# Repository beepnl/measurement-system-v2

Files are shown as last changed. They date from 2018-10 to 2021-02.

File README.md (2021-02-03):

# BEEP - Measurement system
This is a repo containing the files to create the open source hardware for the Beep measurement system.

## Measurement system parts

The measurement system casing is designed as both an electonics/sensor housing, as well as a weighing frame. The outer casing is assembled in four pieces (2 tops, 2 bottoms) out of 18mm thick plate 'Betonplex' (glued multiplex with water resistant top and bottom layer). The wooden top and bottom are connected together by the 2 weight sensor (aluminium) blocks, held in place by 2 weight sensor brackets each. The left and right part are held together with 2 stainless steel tubes, that are screwed on the wood. At one side tightly, using wood parkers, at the other side loosely, using m4 bolts that go inside the inserts. By this connection, the total size of the frame is adjustable for different types of hives. 

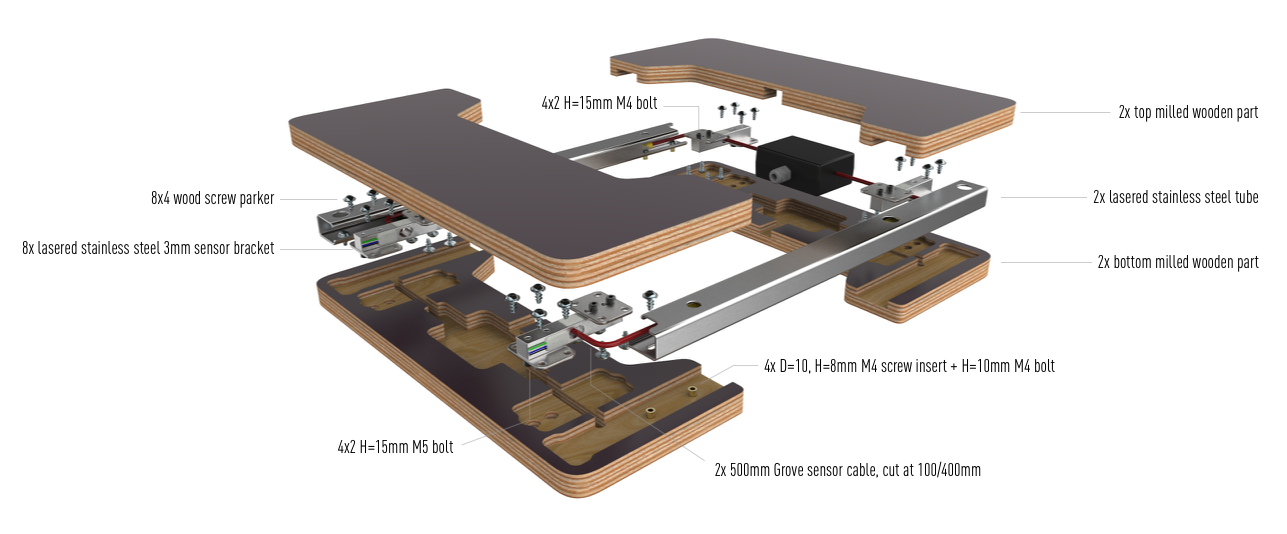
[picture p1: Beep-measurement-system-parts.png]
BEEP measurement system casing


## Frame
The folder 'frame' contains two folders: wood and stainless steel. 

### Wood
The 2D drawings in both Illustrator format and DXF (required by most milling parties).

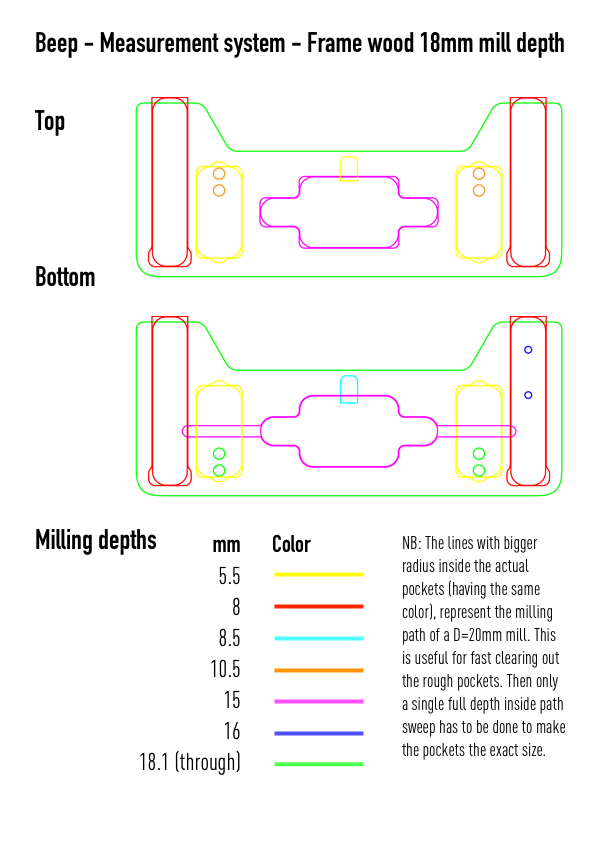
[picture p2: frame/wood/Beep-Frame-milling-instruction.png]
BEEP measurement system casing - Milling instruction


This is a picture of the milling software, with which we mill 42 pieces (21 tops, 21 bottoms) out of an 2440 x 1220 x 18 mm Betonplex.

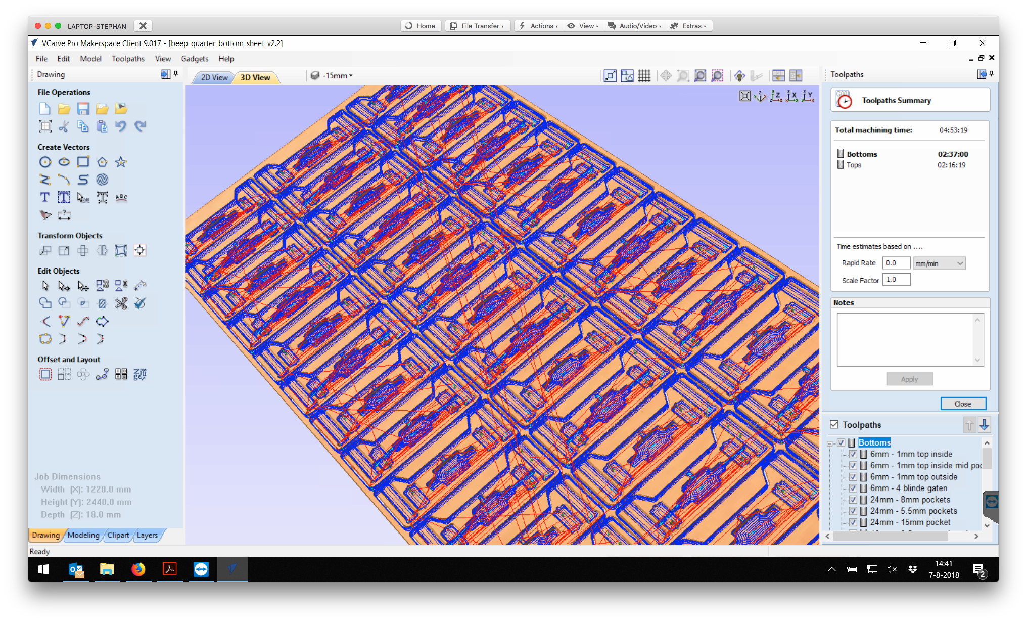
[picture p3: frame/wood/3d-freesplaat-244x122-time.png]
BEEP measurement system - Milling process


### Stainless steel
The 3D and 2D drawings of the stainless steel tube, and the sensor bracket are in this folder. They can be ordered at companies lasering steel.

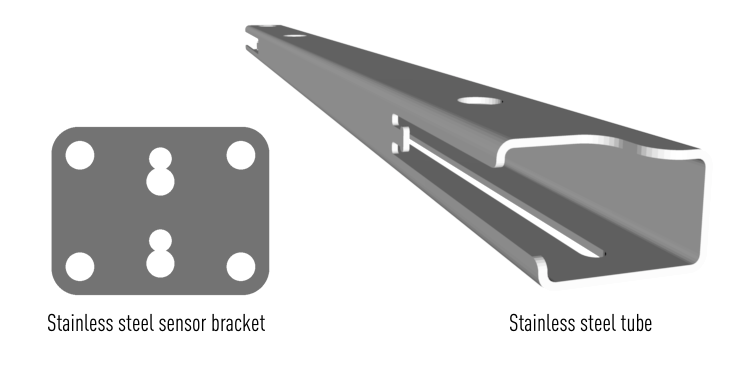
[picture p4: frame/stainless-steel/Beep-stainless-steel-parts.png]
BEEP measurement system - Stainless steel parts


## Electronics
The electronics of the measurement system are bundled together on the Beep PCB, which connects an Arduino, a LoRa (wireless network) chip and the sensors via Grove connectors together.

The folder 'electronics' contains two folders: gerber and kicad.

With the Gerber files, you can directly order a PCB. It contains all files required for the manufacturing of the PCB. 

With the Kicad files, you can edit the PCB and it's components in the open source PCB creation software Kicad (http://kicad-pcb.org/).

### Schematic

*NB: There is an error in the PCB, the one wire temperature sensor DS18b20 cannot work on analog port A7 (the A6 and A7 IO pins can only be used as analog pins, not as digital IO). So you have to use A4, or A5 to connect one wire sensor(s) to. So you also have to add the 4k7 resistor between V+ and the one wire data pin yourself, since the resistor on the PCB is connected to V+ and A7.*

The schematic can be found in the PDF (https://github.com/beepnl/measurement-system-v2/blob/master/electronics/Beep-pcb-v1.4-schematic.pdf)

### PCB
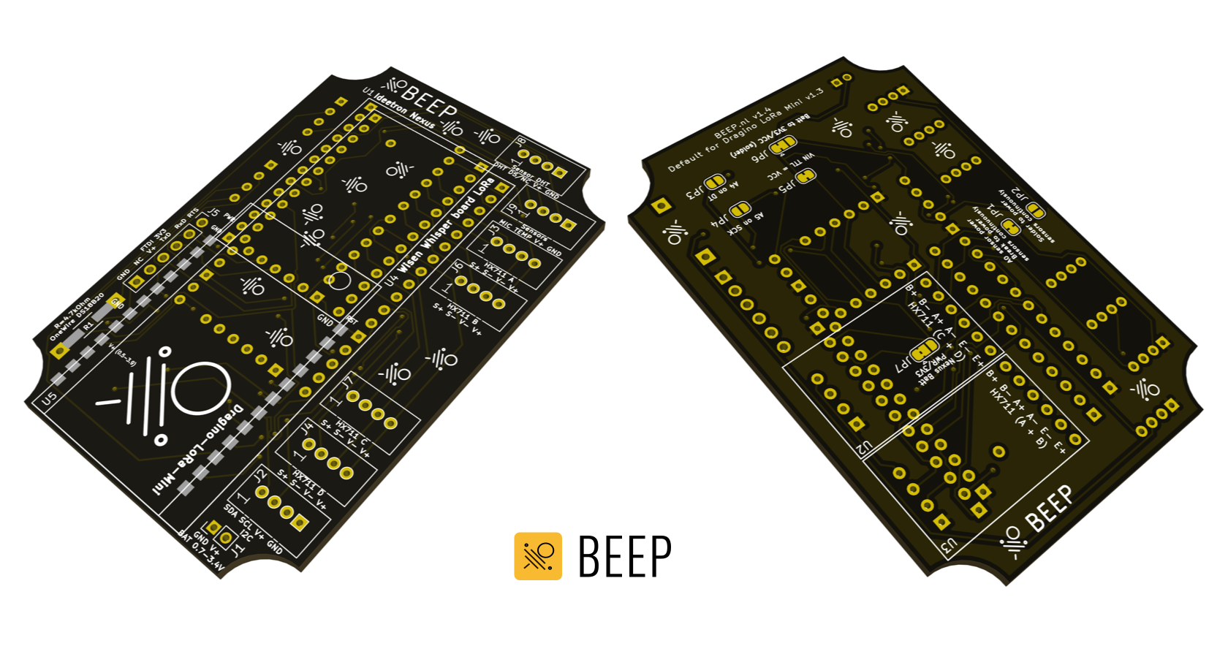
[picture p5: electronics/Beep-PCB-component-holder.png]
BEEP measurement system - PCB


### Assembly
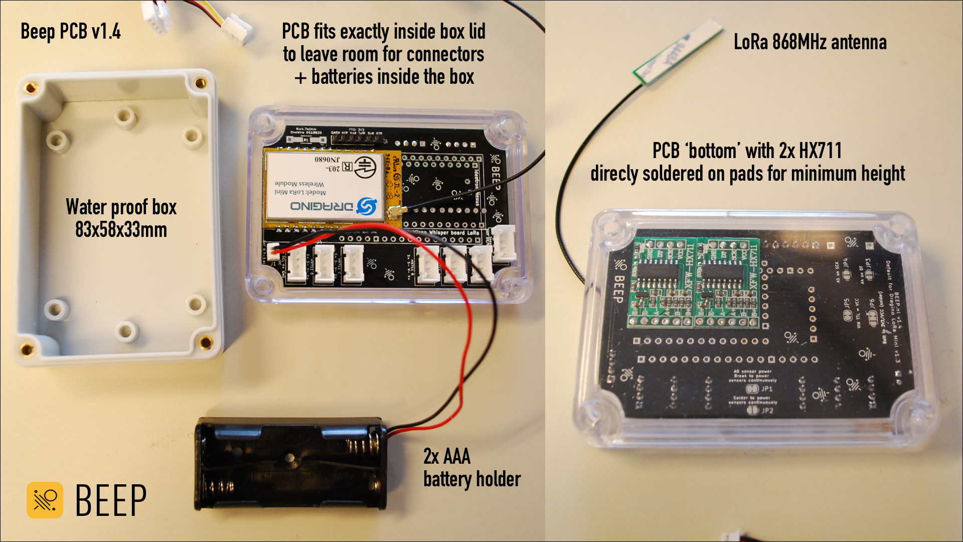
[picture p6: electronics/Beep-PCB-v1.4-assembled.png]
BEEP measurement system - PCB


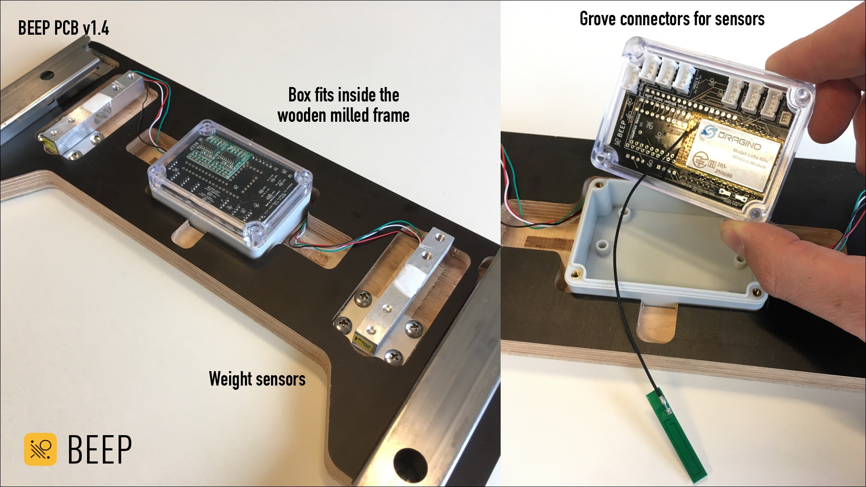
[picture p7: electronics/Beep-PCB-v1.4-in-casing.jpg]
BEEP measurement system - PCB


## Firmware
In the 'firmware' folder, the ultra low power Arduino code is shared to use with the PCB and complete the measurement system.

Place the folder 'Beep-low-power' inside your Arduino folder and set up your own LoRa connection details to send the data.
Send an e-mail to pim@beep.nl, to add your Measurement system Device EUI to your Beep app account and receive it's measurements in the app.

## Improvements
If you have improvements, or ideas for creating a better frame, please send an e-mail to pim@beep.nl explaining your thoughts. Or just fork this repo, and do a pull request with you adjustments, or additions.

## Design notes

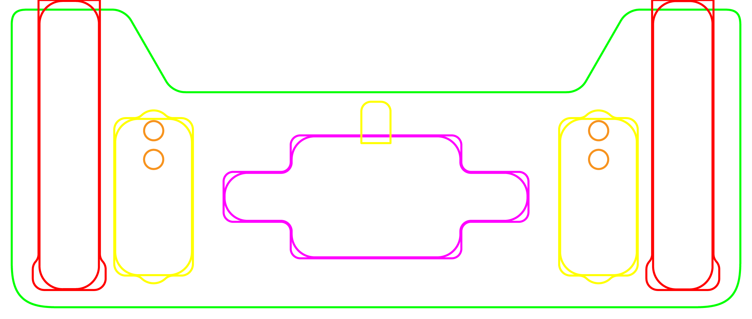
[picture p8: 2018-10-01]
frame/wood/beep_quarter_top_v2.2.png

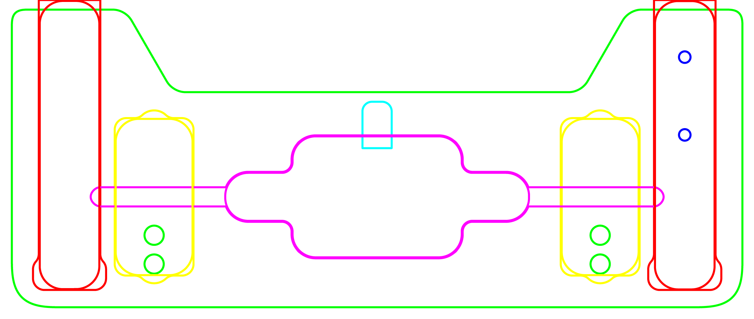
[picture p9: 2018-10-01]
frame/wood/beep_quarter_bottom_v2.2.png

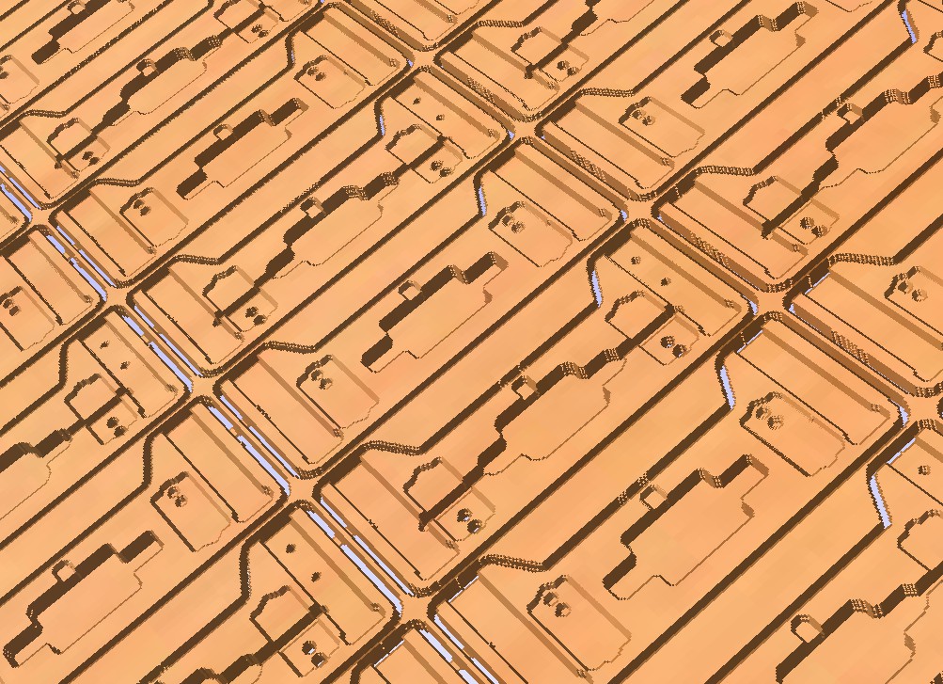
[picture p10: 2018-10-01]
frame/wood/3d-detail-244x122.jpg

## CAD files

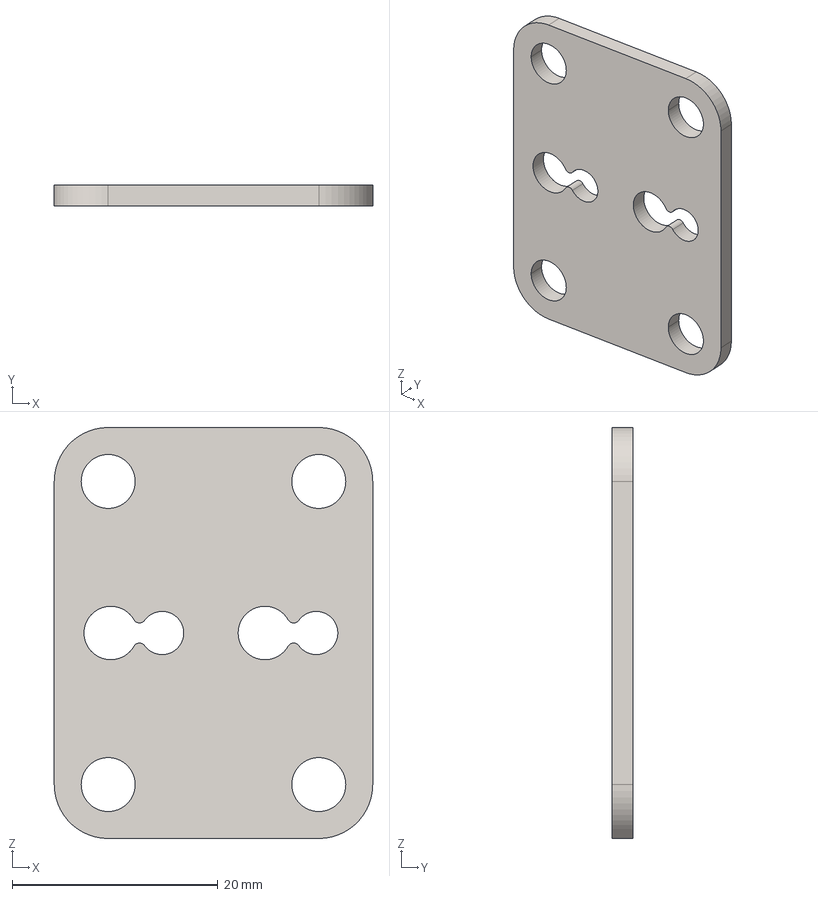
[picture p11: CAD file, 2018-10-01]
frame/stainless-steel/Beep_weightsensor_bracket__2018-05-10.stp
31.0 x 2.00 x 40.0 mm

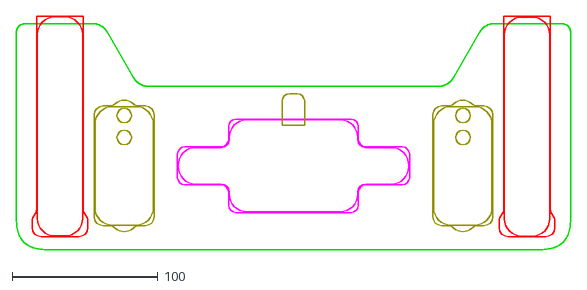
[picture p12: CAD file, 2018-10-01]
frame/wood/beep_quarter_top_v2.2.dxf
380.0 x 160.0

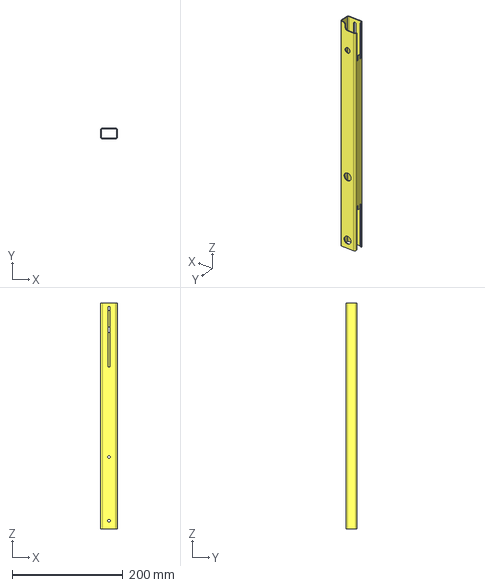
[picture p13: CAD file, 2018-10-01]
frame/stainless-steel/Beep_Tube__2018_07_23.stp
30.0 x 20.0 x 408.5 mm

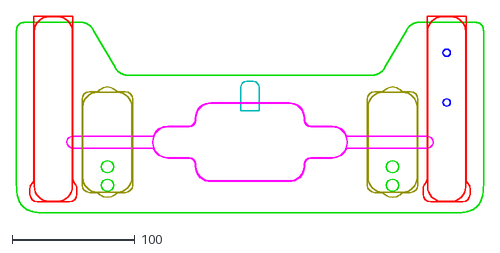
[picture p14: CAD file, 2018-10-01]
frame/wood/beep_quarter_bottom_v2.2.dxf
380.0 x 160.0

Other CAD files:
frame/stainless-steel/Beep_tube__2018_07_23.stl

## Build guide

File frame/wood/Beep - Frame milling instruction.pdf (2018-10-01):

## Beep - Measurement system - Frame wood 18mm mill depth

## Top

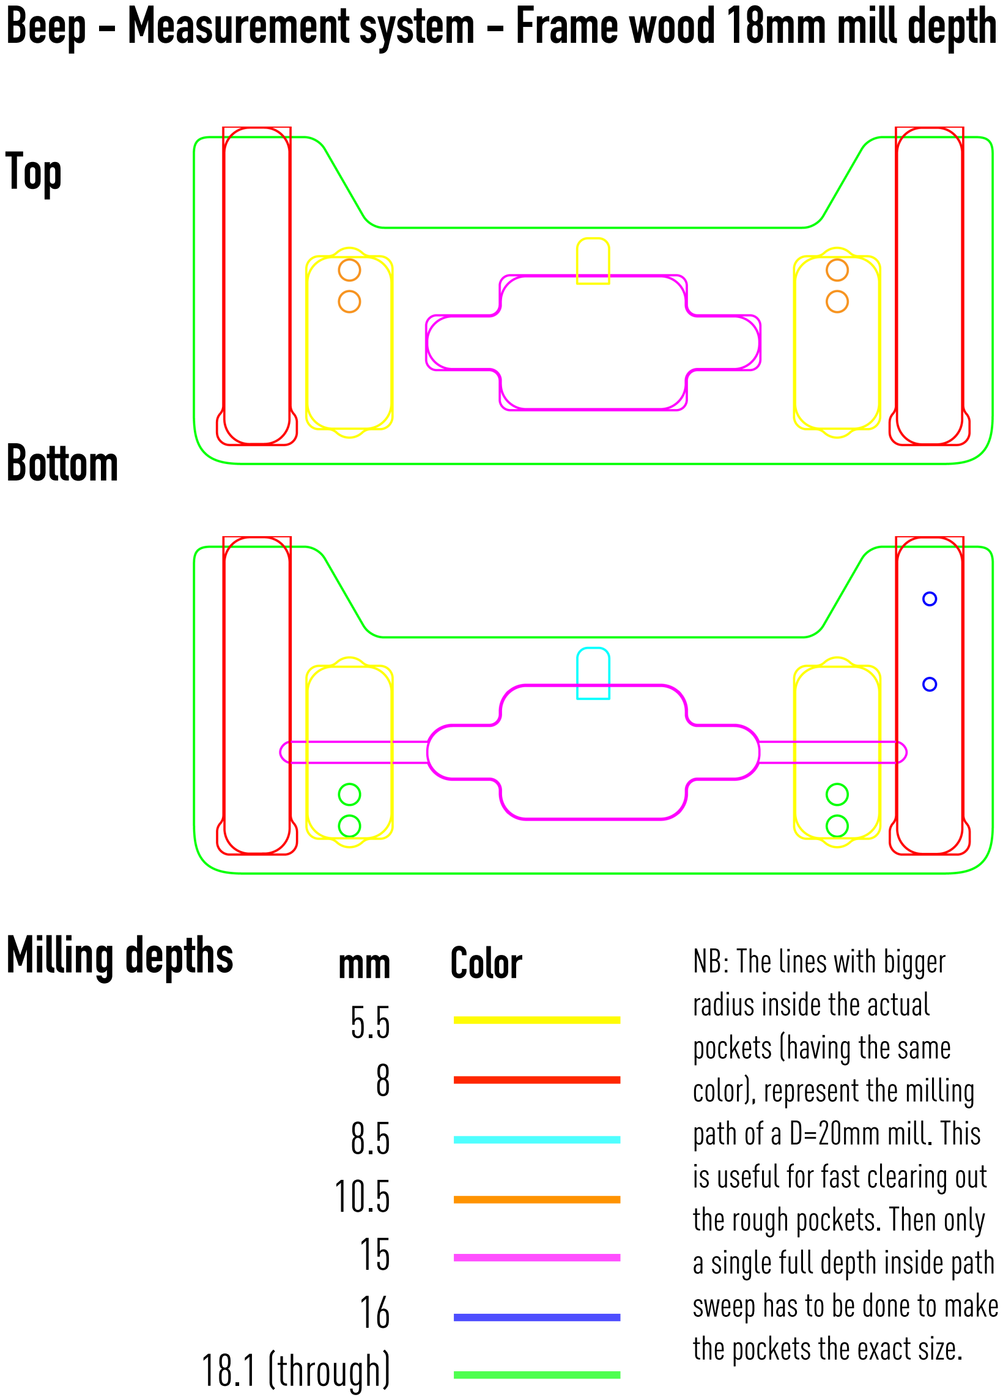
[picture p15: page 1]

## Bottom

Milling depths | mm
| 5.5
| 8
| 8.5
| 10.5
| 15
| 16

## 18.1 (through)

Color | NB: The lines with bigger radius inside the actual pockets (having the same color), represent the milling path of a D=20mm mill. This is useful for fast clearing out the rough pockets. Then only a single full depth inside path sweep has to be done to make the pockets the exact size.

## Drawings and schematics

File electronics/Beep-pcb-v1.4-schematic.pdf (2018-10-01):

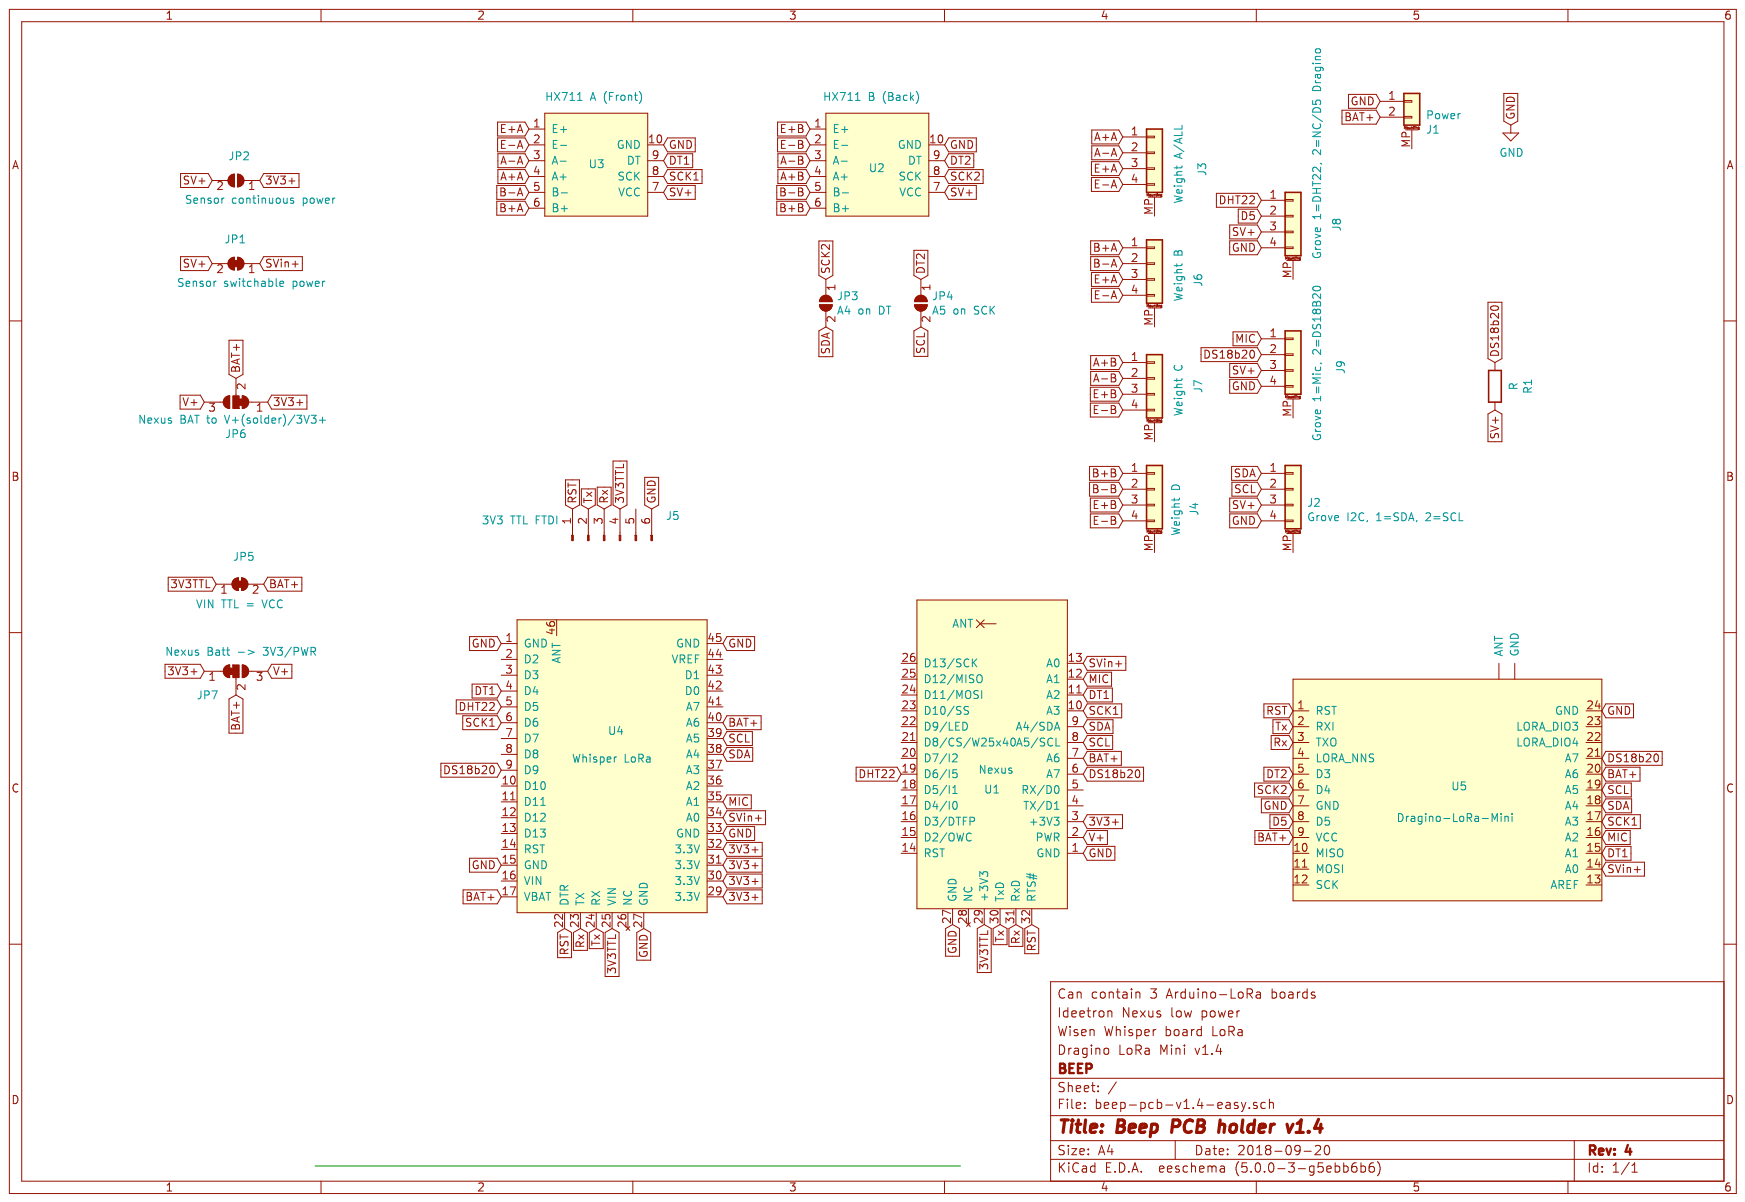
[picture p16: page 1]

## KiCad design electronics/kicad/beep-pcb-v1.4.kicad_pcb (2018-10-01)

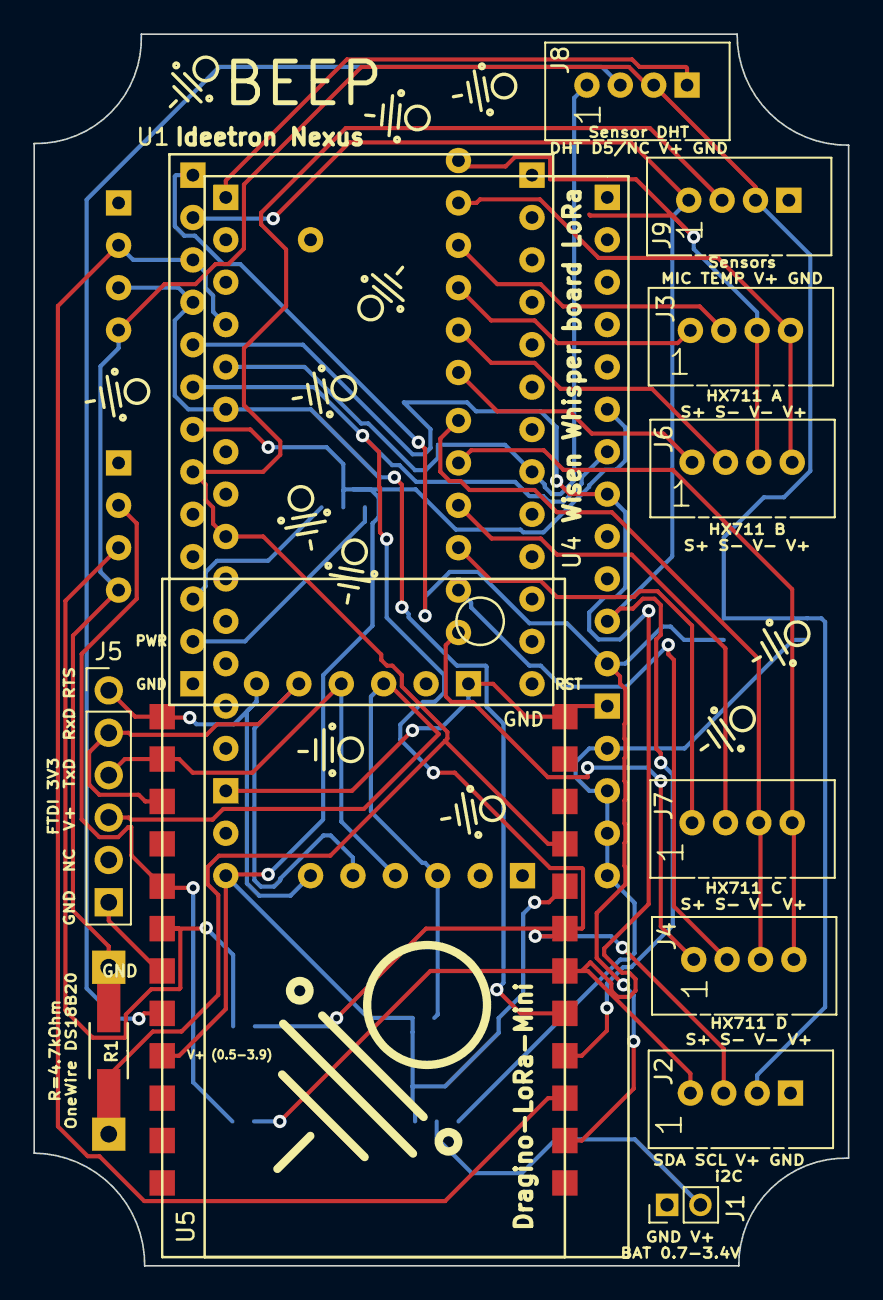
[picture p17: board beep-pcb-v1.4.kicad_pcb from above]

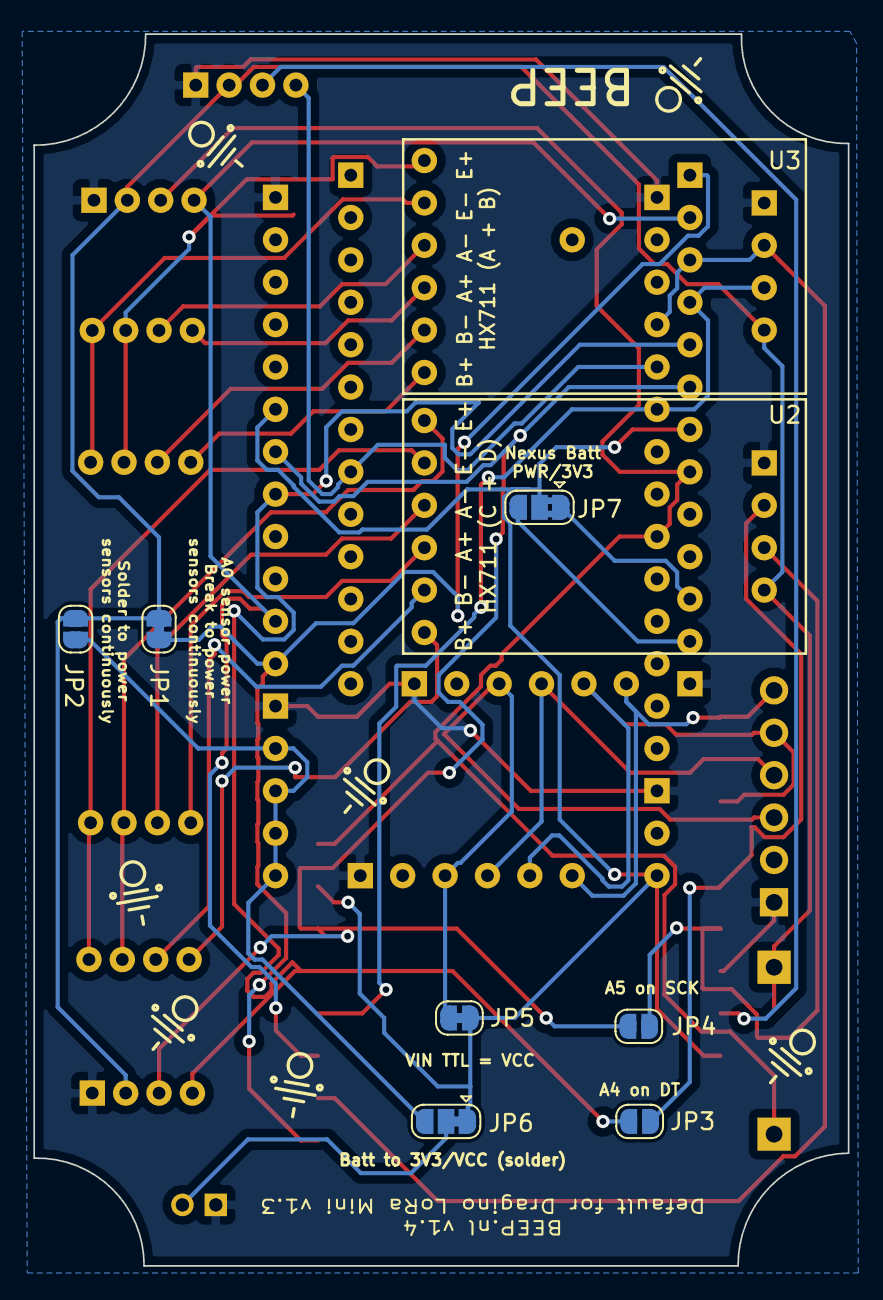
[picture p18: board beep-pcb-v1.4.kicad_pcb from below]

Board: 2 copper layers, 48.8 x 73.8 mm, 22 parts (9 on the bottom side), 34 nets.

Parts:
J1: Power; Pin_Header_Straight_1x02_Pitch2.00mm
J2: Grove I2C, 1=SDA, 2=SCL; Grove_1x04
J3: Weight A/ALL; Grove_1x04
J4: Weight D; Grove_1x04
J5: 3V3 TTL FTDI; Pin_Header_Straight_1x06_Pitch2.54mm
J6: Weight B; Grove_1x04
J7: Weight C; Grove_1x04
J8: Grove 1=DHT22, 2=NC/D5 Dragino; Grove_1x04
J9: Grove 1=Mic, 2=DS18B20; Grove_1x04
JP1: Sensor switchable power; SolderJumper-2_P1.3mm_Bridged_RoundedPad1.0x1.5mm
JP2: Sensor continuous power; SolderJumper-2_P1.3mm_Open_RoundedPad1.0x1.5mm
JP3: A4 on DT; SolderJumper-2_P1.3mm_Open_RoundedPad1.0x1.5mm
JP4: A5 on SCK; SolderJumper-2_P1.3mm_Open_RoundedPad1.0x1.5mm
JP5: VIN TTL = VCC; SolderJumper-2_P1.3mm_Bridged_RoundedPad1.0x1.5mm
JP6: Batt to VCC/3V3 (solder); SolderJumper-3_P1.3mm_Bridged12_RoundedPad1.0x1.5mm
JP7: Nexus Batt -> 3V3/PWR; SolderJumper-3_P1.3mm_Bridged2Bar12_RoundedPad1.0x1.5mm
R1: R; Resistor_SMD+THTuniversal_1206_RM10_HandSoldering
U1: Nexus
U2, U3: HX711
U4: Whisper LoRa; Whisper_Lora
U5: Dragino-LoRa-Mini; Dragino LoRa Mini

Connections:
+3V3: JP2.1, JP6.3, U4.29, U4.30, U4.31, U4.32
+BATT: J1.2, JP6.2
+VDC: JP5.2, JP6.1, JP7.2, U1.7, U4.17, U4.40, U5.9, U5.20
GND: J1.1, J2.4, J5.6, J8.4, J9.4, U1.1, U1.27, U2.10, U3.10, U4.1, U4.15, U4.27, U4.33, U4.45, U5.7, U5.24
unnamed: J2.1, JP3.2, U1.9, U4.38, U5.18
unnamed: J2.2, JP4.2, U1.8, U4.39, U5.19
unnamed: J2.3, J8.3, J9.3, JP1.2, JP2.2, R1.1, U2.7, U3.7
unnamed: J3.1, U3.4
unnamed: J3.2, U3.3
unnamed: J3.3, J6.3, U3.1
unnamed: J3.4, J6.4, U3.2
unnamed: J4.1, U2.6
unnamed: J4.2, U2.5
unnamed: J4.3, J7.3, U2.1
unnamed: J4.4, J7.4, U2.2
unnamed: J5.1, U1.32, U4.22, U5.1
unnamed: J5.2, U1.31, U4.23, U5.3
unnamed: J5.3, U1.30, U4.24, U5.2
unnamed: J5.4, JP5.1, U1.29, U4.25
unnamed: J6.1, U3.6
unnamed: J6.2, U3.5
unnamed: J7.1, U2.4
unnamed: J7.2, U2.3
unnamed: J8.1, U1.19, U4.5
unnamed: J8.2, U5.8
unnamed: J9.1, U1.12, U4.35, U5.15
unnamed: J9.2, R1.2, U1.6, U4.9, U5.21
unnamed: JP1.1, U1.13, U4.34, U5.14
unnamed: JP3.1, U2.9, U5.5
unnamed: JP4.1, U2.8, U5.6
unnamed: JP7.1, U1.3
unnamed: JP7.3, U1.2
unnamed: U1.10, U3.8, U4.6, U5.17
unnamed: U1.11, U3.9, U4.4, U5.16

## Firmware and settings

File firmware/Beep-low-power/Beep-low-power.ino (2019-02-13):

/*******************************************************************************
 * BEEP LoRa code, adjusted for Dragino pinout
 *
 * Many thanks to Ideetron, Maarten Westenberg, Thomas Telkamp and Matthijs Kooijman
 * porting the LMIC stack to Arduino IDE and Gerben den Hartog for his tiny
 * stack implementation with the AES library that we used in the LMIC stack.
 *
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
 * This example sends a valid LoRaWAN packet with sensor values read.
 *
 * Note: LoRaWAN per sub-band duty-cycle limitation is enforced (1% in g1,
 *  0.1% in g2).
 *
 * Change DevAddr to a unique address for your node
 * See http://thethingsnetwork.org/wiki/AddressSpace
 *
 * Define you own LoRa connection details in lorawan_def.h (from row 238):
 * struct.activation_method -> OVER_THE_AIR_ACTIVATION, or ACTIVATION_BY_PERSONALISATION
 * struct.back_end        -> The_Things_Network, KPN (NL)
 * struct.Session, or OTAA (depending on the chosen activation_method)
 *
 * v7 added:
 *     - w_fl, w_fr, w_bl, w_br
 *     - H   -> *2 (range 0-200)
 *     - T   -> -10 -> +40 range (+10, *5), so 0-250 is /5, -10
 *     - W_E -> -20 -> +80 range (/2, +10, *5), so 0-250 is /5, -10, *2
 *
 * v8 added:
 *     - Measurement timing can be set from sensor_sample_sec (min) to max_send_timeout (max)
 *
 * v9 added:
 *     - T/H DHT22 based on SimpleDHT.h, because std DHT.h has timing issue after getBandgap()
 *
 *******************************************************************************/

// Enable debug prints to serial monitor
#define MY_DEBUG_NO // MY_DEBUG_NO (for production), MY_DEBUG_SENS, MY_DEBUG

#if defined(__AVR__)
#include <avr/pgmspace.h>
#include <Arduino.h>
#elif defined(ARDUINO_ARCH_ESP8266)
#include <ESP.h>
#elif defined(__MKL26Z64__)
#include <Arduino.h>
#else
#error Unknown architecture in aes.cpp
#endif

#include <avr/power.h>
#include <avr/sleep.h>
#include <stdbool.h>

#include <LowPower.h>

#include <SPI.h>
#include <EEPROM.h>

#include "AES-128.h"
#include "Encrypt.h"
#include "Nexus_LoRaWAN.h"
#include "spi_nexus.h" // for RFM_sleep function
#include "RFM95.h"
#include "LoRaMAC.h"
#include "timers.h"
#include "lorawan_def.h"

//#include "DHT.h"   // has timing problems in reltion with battery voltage read script
#include <SimpleDHT.h> // so use SimpleDHT.h in stead.
#include "HX711.h"
#include <DS18B20.h> // much smaller than DallasTemperature
//#include <stdlib.h>

/******************************************************************************************
                  PIN DEFINITIONS
******************************************************************************************/

// Audio samples
// Use A2 ADC in free running mode
#define MIC_SENSE_PIN A2
#define SENSOR_POWER A0
#define LOG_OUT 1 // use the logarithmic output function
#define FHT_N 128 // set to 128 point fht (in stead of 256)
#define DIVIDE_FREQ_BY 60 // max freq is 18kHz at 16MHz processor, so factor 60 is max 300Hz sampling, so each band is 5Hz (@FHT_N=128)
#define MEASURE_THRESHOLD 5 // 0-100 threshold for counting values
#include <FHT.h>

// DHT22
#define DHTPIN 5
//#define DHTTYPE DHT22

// Weight sensors
#define DAT_FRONT A1
#define CLK_FRONT A3
#define DAT_BACK 3
#define CLK_BACK 4

// One wire temp DS18B20, does not work on A6/A7 (analog only)
#define ONEW A4

/******************************************************************************************
                  GLOBAL VARIABLES
******************************************************************************************/

bool large_diff = false;

uint8_t  battery_dV        = 0;  // 30 = 3.0V
uint16_t times_not_sent    = 0;  // times not sent counter
uint16_t max_send_timeout  = 3600; // 10800 = 3 hours, 3600 = 1 hour. Has to be a multiple of 8, max 65536 = 1092 min = 18 hour
uint16_t sensor_sample_sec = 904; // 3600 = 1 hour, 904 = 15 min, 296 = 5 min. Has to be a multiple of 8, max 65536 = 1092 min = 18 hour

  // Interrupt variables.
  volatile bool LORA_SEND;

  double read_supply_voltage (void);

  sAPP        app;    //  Application variables
  sLoRaWAN    lora;   //  See the Nexus_Lorawan.h file for the settings of this structure.

  // Initialize the LoRaWAN stack.
  LORAMAC     lorawan (&lora);

/******************************************************************************************
                  INTERRUPTS
******************************************************************************************/
/*
  @Brief  Interrupt vector for the alarm of the MCP7940 Real Time Clock.
*/
ISR(INT1_vect)
{
  // Set the boolean to true to indicate that the RTC alarm has occurred. Do not use I2C functions or long delays here, but handle that in the main loop.
  LORA_SEND = true;
}

/*
  @Brief  Interrupt vector for Timer1 which is used to time the Join and Receive windows for timeslot 1 and timelsot 2
*/
ISR(TIMER1_COMPA_vect)
{
  // Increment the timeslot counter variable for timing the JOIN and receive delays.
  lora.timeslot++;
}


/******************************************************************************************
                  SENSOR
******************************************************************************************/

// FHT
uint16_t sound_total    = 0;
uint16_t sound_bee_fan4 = 0;
uint16_t sound_bee_fan6 = 0;
uint16_t sound_bee_fan9 = 0;
uint16_t sound_bee_fly  = 0;

float w_fl_offset = 0;
float w_fr_offset = 0;
float w_bl_offset = 0;
float w_br_offset = 0;

uint8_t w_e_hist[] = {0,0,0};
uint8_t t_e_hist[] = {0,0,0};
uint8_t t_i_hist[] = {0,0,0};
uint8_t h_e_hist[] = {0,0,0};
uint8_t s_t_hist[] = {0,0,0};
uint8_t b_v_hist[] = {0,0,0};

// HX711
int16_t weight_calib = 5000; // -5000 for red to E+ and black to E-, else 5000
HX711 weight_front(DAT_FRONT, CLK_FRONT);
HX711 weight_back(DAT_BACK, CLK_BACK);

// DHT 22
SimpleDHT22 dht(DHTPIN);
//DHT dht(DHTPIN, DHTTYPE);

// One wire
OneWire oneWire(ONEW);
DS18B20 sensor(&oneWire);

/******************************************************************************************
                  FUNCTIONS
******************************************************************************************/

// big == true defines if arr is uint16_t (otherwise uint8_t)
uint8_t shiftAndCalculatePercDiff(uint8_t arr[], uint8_t value)
{
  int i;
  float    ave = 0;
  uint16_t sum = 0;
  uint8_t  cnt = 0;

  #ifdef MY_DEBUG_SENS
    Serial.print(F("["));
    for (i = 0; i < 3; i++)
    {
      Serial.print(arr[i]);
      Serial.print(F(","));
    }
    Serial.print(F("]"));
  #endif

  // calculate average
  for (i = 0; i < 3; i++)
  {
    uint8_t val = arr[i];
    if (val > 0)
    {
      sum += val;
      cnt += 1;
    }
  }
  ave = sum / max(1, cnt);

  // push and shift value
  for (i = 2; i > -1; i--)
  {
    if (i > 0)
    {
      arr[i] = arr[i-1]; // 2->*, 1->2, 0->1
    }
    else // push first array value
    {
      arr[i] = value;
    }
  }

  float  dif = value - ave;
  float  fra = (ave == 0) ? dif : (dif / ave);
  int8_t inc = min(127, max(-127, round(100 * fra) ));

  #ifdef MY_DEBUG_SENS
    Serial.print(F(", ave="));
    Serial.print(ave);
    Serial.print(F(", val="));
    Serial.print(value);
    Serial.print(F(", dif="));
    Serial.print(dif);
    Serial.print(F(", inc="));
    Serial.print(inc);
    Serial.print(F("%"));
    Serial.println();
  #endif

  return abs(inc);
}

// Saves the value to the history array and calculates the diff % with
// Sensor char 'w', 't', 'h', 'i', 's', 'b'
uint8_t saveValueAndReturnDiff(char sensor, uint16_t value)
{
  uint8_t diff_perc = 0;

  #ifdef MY_DEBUG_SENS
    Serial.print(F(", "));
    Serial.print(sensor);
  #endif

  if (value == 0 && (sensor != 'w' && sensor != 's')) // do not place 0 value in history, because it is an error value
  {
    Serial.println(F(" ZERO VALUE"));
    return 0;
  }

  switch(sensor){
    case 'w':
      diff_perc = shiftAndCalculatePercDiff(w_e_hist, value);
      if (diff_perc > 2)
        large_diff = true;
      break;
    case 't':
      diff_perc = shiftAndCalculatePercDiff(t_e_hist, value);
      if (diff_perc > 5)
        large_diff = true;
      break;
    case 'h':
      diff_perc = shiftAndCalculatePercDiff(h_e_hist, value);
      break;
      if (diff_perc > 15)
        large_diff = true;
    case 'i':
      diff_perc = shiftAndCalculatePercDiff(t_i_hist, value);
      if (diff_perc > 3)
        large_diff = true;
      break;
    case 's':
      diff_perc = shiftAndCalculatePercDiff(s_t_hist, value);
      if (diff_perc > 50)
        large_diff = true;
      break;
    case 'b':
      diff_perc = shiftAndCalculatePercDiff(b_v_hist, value);
      if (diff_perc > 3)
        large_diff = true;
      break;
  }

  return diff_perc;
}


// Sensor range -10 to +61 => 0x00 == invalid to low, 0xFF is invalid too high
byte tempify(float val)
{
  if(val <= -10)
    return 0;

  if(val >= 41)
    return 255;

  return round(5 * (val + 10));
}

// Sensor range 0 to +655.35 => 0x00 == invalid to low, 0xFFFF is invalid too high
uint16_t floatify(float val)
{
  if(val < 0)
    return 0;

  if(val > 655.35)
    return 65535;

  return round(val * 100);
}

// Sensor range 0 to +218.45 => 0x00 == invalid to low, 0xFFFF is invalid too high
uint16_t weightify(float val)
{
  return floatify(val * 3);
}



// FHT Audio

void sumSounds()
{
  sound_bee_fan9 += normFhtLog(39) + normFhtLog(40);
  sound_bee_fan6 += normFhtLog(47) + normFhtLog(48);
  sound_bee_fly  += normFhtLog(52) + normFhtLog(53);
  sound_bee_fan4 += normFhtLog(59) + normFhtLog(60);

  for (byte i = 7 ; i < FHT_N/2 ; i++) // max bands: FHT_N/2, first 2 to 7 bands are always full
  {
    int add = normFhtLog(i);
    if (sound_total + add < 65535)
      sound_total += add;
  }

}

int normFhtLog(byte i)
{
  return (byte)min(9, fht_log_out[i] * MEASURE_THRESHOLD / 255);
}

void emptyLog()
{
  sound_bee_fan9 = 0;
  sound_bee_fan6 = 0;
  sound_bee_fly  = 0;
  sound_bee_fan4 = 0;
  sound_total    = 0;
}

void sample_audio()
{
  if (battery_dV < 24) // do not measure if voltage is below 2.4V
    return;

  //pinMode(MIC_SENSE_PIN, INPUT);

  ADCSRA = 0xe5; // set the adc to free running mode

  if (MIC_SENSE_PIN == A0)
  {
    ADMUX  = 0x40; // use adc0 (adc0 = 0x40, adc1=0x41, adc1=0x42)
    DIDR0  = B00000001; // turn off the digital input for adc0 of adc 8->0
  }
  else if (MIC_SENSE_PIN == A1)
  {
    ADMUX  = 0x41; // use adc1 (adc0 = 0x40, adc1=0x41, adc1=0x42)
    DIDR0  = B00000010; // turn off the digital input for adc1 of adc 8->0
  }
  else if (MIC_SENSE_PIN == A2)
  {
    ADMUX  = 0x42; // use adc2 (adc0 = 0x40, adc1=0x41, adc1=0x42)
    DIDR0  = B00000100; // turn off the digital input for adc2 of adc 8->0
  }
  else if (MIC_SENSE_PIN == A3)
  {
    ADMUX  = 0x43; // use adc3 (adc0 = 0x40, adc1=0x41, adc1=0x42)
    DIDR0  = B00001000; // turn off the digital input for adc3 of adc 8->0
  }
  else if (MIC_SENSE_PIN == A4)
  {
    ADMUX  = 0x44; // use adc4 (adc0 = 0x40, adc1=0x41, adc1=0x42)
    DIDR0  = B00010000; // turn off the digital input for adc4 of adc 8->0
  }
  else if (MIC_SENSE_PIN == A5)
  {
    ADMUX  = 0x45; // use adc5 (adc0 = 0x40, adc1=0x41, adc1=0x42)
    DIDR0  = B00100000; // turn off the digital input for adc5 of adc 8->0
  }

  //printDebug();
  delay(500);

  cli();  // UDRE interrupt slows this way down on arduino1.0

  TIMSK0 = 0; // turn off timer0 for lower jitter
  for (int i = 0 ; i < FHT_N ; i++) { // save 256 samples

    ADCSRA = 0xf5; // restart adc

    // Cut down freq to Freq_max / DIVIDE_FREQ_BY (10 ~= 900Hz)
    long adc_l = 0;
    long adc_h = 0;
    for ( int8_t inner = 0; inner < DIVIDE_FREQ_BY; inner++)
    {
      ADCSRA |= (1<<ADSC);
      while(!(ADCSRA & 0x10));
      adc_l = adc_l + ADCL;
      adc_h = adc_h + ADCH;
    }
    adc_l = adc_l / DIVIDE_FREQ_BY;
    adc_h = adc_h / DIVIDE_FREQ_BY;

    // while(!(ADCSRA & 0x10)); // wait for adc to be ready
    byte m = max(0,min(255,adc_l)); // fetch adc data
    byte j = max(0,min(255,adc_h));

    //byte m = ADCL; // fetch adc data
    //byte j = ADCH;
    int k = (j << 8) | m; // form into an int
    k -= 0x0200; // form into a signed int
    k <<= 6; // form into a 16b signed int
    fht_input[i] = k; // put real data into bins
  }
  TIMSK0 = 1; // turn on timer0

  fht_window(); // window the data for better frequency response
  fht_reorder(); // reorder the data before doing the fht
  fht_run(); // process the data in the fht
  fht_mag_log(); // take the output of the fht

  sumSounds();

  sei(); // enable interrupt again

  ADMUX  = 0x00; // use user defined ADC
  ADCSRA = 0x87; // release ADC -> Analog comparator

  #ifdef MY_DEBUG_SENS
    Serial.print(F(", s9="));
    Serial.print(sound_bee_fan9);
    Serial.print(F(", fan6="));
    Serial.print(sound_bee_fan6);
    Serial.print(F(", fan4="));
    Serial.print(sound_bee_fan4);
    Serial.print(F(", fly="));
    Serial.print(sound_bee_fly);
    Serial.print(F(", sound="));
    Serial.print(sound_total);
  #endif

  lora.TX.Data[6]= sound_total;
  lora.TX.Data[7]= sound_bee_fan4;
  lora.TX.Data[8]= sound_bee_fan6;
  lora.TX.Data[9]= sound_bee_fan9;
  lora.TX.Data[10]= sound_bee_fly;

  emptyLog(); // empy sound log

  saveValueAndReturnDiff('s', sound_total);
}


void get_sensor_weight()
{
  if (battery_dV < 27) // do not measure if voltage is below 2.6V
    return;

  //delay(500);

  weight_front.power_up();
  weight_front.set_scale(weight_calib);
  //weight_front.power_down();

  weight_back.power_up();
  weight_back.set_scale(weight_calib);
  //weight_back.power_down();

  byte weight_channel_a = 64;
  byte weight_channel_b = 32;

  uint16_t weight_max = 1000; // max value of weight
  uint16_t w_fl = 0;
  uint16_t w_fr = 0;
  uint16_t w_bl = 0;
  uint16_t w_br = 0;
  uint16_t w_e = 0;

  float w_fl_f = 0;
  float w_fr_f = 0;
  float w_bl_f = 0;
  float w_br_f = 0;

  float w_val = 0;

  bool first_time = false;

  if (w_fl_offset == 0 && w_fr_offset == 0 && w_bl_offset == 0 && w_br_offset == 0)
    first_time = true;

  //weight_front.power_up();

  delay(100);

  byte oversample = 3; // 1 time is fast, more becomes slow

  weight_front.set_gain(weight_channel_a);
  w_val = weight_front.get_units(oversample);
  if (w_fl_offset == 0)
    w_fl_offset = w_val;

  w_fl_f = abs(w_val - w_fl_offset);
  w_fl   = weightify(w_fl_f);

  weight_front.set_gain(weight_channel_b);
  w_val = weight_front.get_units(oversample) * 2;  // multiply by 2 because channel gain is 2x as low
  if (w_fr_offset == 0)
    w_fr_offset = w_val;

  w_fr_f = abs(w_val - w_fr_offset);
  w_fr   = weightify(w_fr_f);

  //weight_back.power_up();

  //delay(100);

  weight_back.set_gain(weight_channel_a);
  w_val = weight_back.get_units(oversample);
  if (w_bl_offset == 0)
    w_bl_offset = w_val;

  w_bl_f = abs(w_val - w_bl_offset);
  w_bl   = weightify(w_bl_f);

  weight_back.set_gain(weight_channel_b);
  w_val = weight_back.get_units(oversample) * 2;  // multiply by 2 because channel gain is 2x as low
  if (w_br_offset == 0)
    w_br_offset = w_val;

  w_br_f = abs(w_val - w_br_offset);
  w_br   = weightify(w_br_f);

  weight_front.power_down();
  weight_back.power_down();


  int count = 0;
  if (w_fl_f > 1)
    count++;

  if (w_fr_f > 1)
    count++;

  if (w_bl_f > 1)
    count++;

  if (w_br_f > 1)
    count++;

  w_val = 0;
  w_val += w_fl_f;
  w_val += w_fr_f;
  w_val += w_bl_f;
  w_val += w_br_f;
  w_val /= max(1, count);

  w_e = min(254, round(w_val));

  #ifdef MY_DEBUG_SENS
    if (first_time)
    {
      Serial.print(F(", W_FL_OFS="));
      Serial.print(w_fl_offset);
      Serial.print(F(", W_FR_OFS="));
      Serial.print(w_fr_offset);
      Serial.print(F(", W_BL_OFS="));
      Serial.print(w_bl_offset);
      Serial.print(F(", W_BR_OFS="));
      Serial.print(w_br_offset);
    }
    else
    {
      Serial.print(F(", W_FL="));
      Serial.print(w_fl_f);
      Serial.print(F(", W_FR="));
      Serial.print(w_fr_f);
      Serial.print(F(", W_BL="));
      Serial.print(w_bl_f);
      Serial.print(F(", W_BR="));
      Serial.print(w_br_f);
      Serial.print(F(", W_E="));
      Serial.print(w_val);
    }
  #endif

  saveValueAndReturnDiff('w', w_e);

  lora.TX.Data[2]  = w_e;
  lora.TX.Data[11] = highByte(w_fl);
  lora.TX.Data[12] = lowByte(w_fl);
  lora.TX.Data[13] = highByte(w_fr);
  lora.TX.Data[14] = lowByte(w_fr);
  lora.TX.Data[15] = highByte(w_bl);
  lora.TX.Data[16] = lowByte(w_bl);
  lora.TX.Data[17] = highByte(w_br);
  lora.TX.Data[18] = lowByte(w_br);

}

void get_sensor_simple_dht()
{
  if (battery_dV < 30) // do not measure if voltage is below 3.0V
    return;

  float t_e = 0;
  float h_e = 0;
  int err = SimpleDHTErrSuccess;
  if ((err = dht.read2(&t_e, &h_e, NULL)) != SimpleDHTErrSuccess) {
    #ifdef MY_DEBUG_SENS
      Serial.println(F("DHT read error"));
    #endif
    return;
  }
  
  #ifdef MY_DEBUG_SENS
    Serial.print(F(", T_E="));
    Serial.print(t_e);
    Serial.print(F(", H_E="));
    Serial.print(h_e);
  #endif

  uint8_t t = 0;
  uint8_t h = 0;

  if (!isnan(t_e))
    t = tempify(t_e);

  if (!isnan(h_e))
    h = round(h_e * 2);

  saveValueAndReturnDiff('t', t);
  saveValueAndReturnDiff('h', h);

  lora.TX.Data[0] = t;
  lora.TX.Data[1] = h;
}

void get_sensor_one_wire()
{
  if (battery_dV < 30) // do not measure if voltage is below 3.0V
    return;

  float t_i = 0;

  sensor.begin(); // One wire
  sensor.setResolution(11);
  sensor.requestTemperatures();

  bool       err = false;
  uint32_t milis = millis();

  while (!sensor.isConversionComplete())
  {
    if (millis() - milis > 1000)
    {
      err = true;
      break;
    }
  };

  t_i = sensor.getTempC();

  uint8_t t = 0;
  if (err || t_i < -10 || t_i > 41)
    t = 0;
  else
    t = tempify(t_i);

  #ifdef MY_DEBUG_SENS
    Serial.print(F(", T_I="));
    Serial.println(t_i);

    if (err)
      Serial.print(F(" (ERR)"));
  #endif

  saveValueAndReturnDiff('i', t);

  lora.TX.Data[3] = t;
}
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
void loop()
{
  printStringAndHex("LoRa DEV EUI: ", &(lora.OTAA.DevEUI[0]), 8);

  lorawan.OTAA_connect();
  RFM_Sleep();

  // Super loop
  while(1)
  {

    // Measure
    read_sensors();

    if (battery_dV > 18) // do not measure if voltage is below 1.8V
    {
      if (large_diff || (times_not_sent * sensor_sample_sec) >= max_send_timeout )
      {
        send_lora_msg();
        times_not_sent = 0;
        large_diff     = false;
      }
      else
      {
        times_not_sent++;
      }
    }
    // Go to POWER_DOWN_MODE to reduce power consumption when the Arduino has nothing to do.
    sleep(sensor_sample_sec);

  }//While(1)
}


void sleep(uint16_t seconds)
{
  #ifdef MY_DEBUG_SENS
  Serial.print(F("zzz for "));
  Serial.print(seconds);
  Serial.println(F(" sec..."));
  Serial.flush();
  #endif

  RFM_Sleep();
  turn_off();
  for (int i=0; i<int(seconds/8); i++)
  {
    // Use library from https://github.com/rocketscream/Low-Power
    LowPower.powerDown(SLEEP_8S, ADC_OFF, BOD_OFF);
  }
  turn_on();
  RFM_Sleep();
}

void RFM_Sleep()
{
  // Set RFM to sleep mode
  SPI_Write(RFM_NSS, 0x01, 0x00);
  //Wait until RFM is in sleep mode
  delay(10);
}

void RFM_Wakeup()
{
  //Set RFM in LoRa mode
  SPI_Write(RFM_NSS, 0x01, 0x80);
  //Wait until RFM is powered up
  delay(250);
}


/*
  @brief
    Function which disables all IO's that can leak current through
*/
void turn_off (void)
{
  digitalWrite(SENSOR_POWER, LOW);

  // power off IO's
  digitalWrite(DHTPIN, LOW);
  digitalWrite(DAT_BACK, LOW);
  digitalWrite(CLK_BACK, LOW);
  digitalWrite(DAT_FRONT, LOW);
  digitalWrite(CLK_FRONT, LOW);
  digitalWrite(ONEW, LOW);

  pinMode(DHTPIN, OUTPUT);
  pinMode(DAT_BACK, OUTPUT);
  pinMode(CLK_BACK, OUTPUT);
  pinMode(DAT_FRONT, OUTPUT);
  pinMode(CLK_FRONT, OUTPUT);
  pinMode(ONEW, OUTPUT);

}

void turn_on (void)
{
  pinMode(DAT_BACK, INPUT);
  pinMode(DAT_FRONT, INPUT);
  pinMode(DHTPIN, INPUT);
}

/*
  @brief
    Function to print a string of text and an array of data in hexadecimal format.
  @parameters
    String  String of characters, must be zero terminated.
    data  Pointer to the array that must be printed in hexadecimal format
    n   Number of bytes that must be printed out in hexadecimal
*/
void printStringAndHex(const char *String, uint8_t *data, uint8_t n)
{
  #ifdef MY_DEBUG_SENS
    uint8_t i;

    Serial.print(String);
    Serial.flush();
    Serial.print(n, DEC);
    Serial.print(" bytes; ");

    // Print the data as a hexadecimal string
    for( i = 0 ; i < n ; i++)
    {
      // Print single nibbles, since the Hexadecimal format printed by the Serial.Print function does not print leading zeroes.
      Serial.print((unsigned char) ((data[i] & 0xF0) >> 4), HEX); // Print MSB first
      Serial.print((unsigned char) ((data[i] & 0x0F) >> 0), HEX); // Print LSB second
      Serial.print(' ');
      Serial.flush();
    }
    Serial.println();
  #endif
}


/*
  @brief
    Function to handle incoming data from an confirmed message up. If there is a single received byte and it's value is not zero, the
    value will be written to the LoRaWAN message interval and the RTC will be set to send a LoRaWAN message in the given number of minutes.
*/
void handle_reply (void)
{
  // Check if there is a single byte in the reply message from the back-end, if so retrieve it and copy it's contents to the LoRaWAN message interval
  if(lora.RX.Count == 1)
  {
    // Copy the received byte and reconfigure the LoRaWAN message interval when the received byte isn't zero.
    if(lora.RX.Data[0] != 0)
    {
      app.LoRaWAN_message_interval = lora.RX.Data[0];
      Serial.print(F("LoRaWAN_message_interval: "));
      Serial.println(app.LoRaWAN_message_interval);
      // Reconfigure the RTC for an interrupt on the next interval.
      // mcp7940_reset_minute_alarm(app.LoRaWAN_message_interval);
    }
  }
}

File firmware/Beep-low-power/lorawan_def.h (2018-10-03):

/******************************************************************************************
* Copyright 2017 Ideetron B.V.
*
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
* You should have received a copy of the GNU Lesser General Public License
* along with this program.  If not, see <http://www.gnu.org/licenses/>.
******************************************************************************************/
/****************************************************************************************
* File:     lorawan_def.h
* Author:   Gerben den Hartog
* Company:	Ideetron B.V.
* Website:  http://www.ideetron.nl/LoRa
* E-mail:   info@ideetron.nl
* Created on:         06-02-2017
* Supported Hardware: ID150119-02 Nexus board with RFM95
****************************************************************************************/


#ifndef STRUCT_H
#define STRUCT_H

	#include <stdint.h>
	#include <stdbool.h>

	#define LORA_FIFO_SIZE			64
	#define CFLIST_FREQUENCIES_MAX	5
	#define DEFAULT_FREQUENCIES		3
	#define LORAWAN_MAX_PAYLOAD		52

	/*********************************************************************************************
										ENUMERATION DEFENITIONS
	*********************************************************************************************/
	// LoRaWAN Mote class specification
	typedef enum
	{
		CLASS_A,
		//CLASS_B,
		CLASS_C
	}eLoRaWAN_MOTE_CLASS;

	// Enumeration to set the used back-end and use the TX and RX settings for that particular back-end.
	typedef enum
	{
		MANUAL,				//	Manual mode for setting the TX and RX channels and data rate for OTAA and data messages
		SEMTECH,			//	Semtech's the patent holder for the LoRaWAN chips.
		The_Things_Network,	//	The Things Industries back-end, which is only functional for OTAA motes. ABP is barely supported and the service may have some downtime from time-to-time for maintenance.
		KPN					//	The Dutch full-coverage LoRaWAN network provider in the Netherlands, which has LoRaWAN localization capabilities, but it's services come at a  cost.
	}eBACKENDS;

	/* MAC HEADER types */
	typedef enum
	{
		JOIN_REQUEST            = 0x00, // 0000 0000
		JOIN_ACCEPT             = 0x20, // 0010 0000
		UNCONFIRMED_DATA_UP     = 0x40, // 0100 0000
		UNCONFIRMED_DATA_DOWN   = 0x60, // 0110 0000
		CONFIRMED_DATA_UP       = 0x80, // 1000 0000
		CONFIRMED_DATA_DOWN     = 0xA0, // 1010 0000
		CONFIRMED_BITMASK		= 0x80,
		UNCONFIRMED_BITMASK		= 0x40,
		INIT_VAL				= 0x00
	}eMESSAGE_TYPES;

	// Receive delay enumeration for OTAA Join Delay and message delays.
	typedef enum
	{
 		JOIN_DELAY_1   = 4900,
 		JOIN_DELAY_2   = 5900,
		RECEIVE_DELAY1 = 900,
		RECEIVE_DELAY2 = 1900
	}eRECEIVE_DELAY;


	// Direction enumeration for the MIC calculation. See page 20, chapter 4.3.3 of the Lora Specification 1.02
	 typedef enum
	 {
		 UPSTREAM_DIR    = 0,    //  Uplink   (Away from mote)
		 DOWNSTREAM_DIR  = 1     //  Downlink (towards the mote)
	 }eDIRECTION;

	// LoRaWAN Datarates
	typedef enum
	{
		SF12_BW125kHz = 0x01,
		SF11_BW125kHz = 0x02,
		SF10_BW125kHz = 0x03,
		SF09_BW125kHz = 0x04,
		SF08_BW125kHz = 0x05,
		SF07_BW125kHz = 0x06,
		SF07_BW250kHz = 0x07,
		SF09_BW500kHz = 0x08,
		SF_BITMASK    = 0x03
	}eLoRaWAN_DATARATES;

	// Channel enumeration
	typedef enum
	{
		CH00_868_100,
		CH01_868_300,
		CH02_868_500,
		CFLIST_INDEX_1,
		CFLIST_INDEX_2,
		CFLIST_INDEX_3,
		CFLIST_INDEX_4,
		CFLIST_INDEX_5,
		CH03_867_100,
		CH04_867_300,
		CH05_867_500,
		CH06_867_700,
		CH07_867_900,
		CH10_869_525
	}eLoRaWAN_CHANNELS;

	// Confirmed and unconfirmed messages type enumeration.
	typedef enum
	{
		UNCONFIRMED,
		CONFIRMED
	}eCONFIRMATION;

	// Activation methods
	typedef enum
	{
		ACTIVATION_BY_PERSONALISATION,
		OVER_THE_AIR_ACTIVATION
	}eMOTE_NETWORK_JOIN;

	//return values for the RFM95
	typedef enum
	{
		INIT,				//0 	Initialization error return code
		CRC_OK,				//1		CRC of the received message is incorrect, indicating an incomplete or corrupted message
		CRC_NOK,			//2		CRC of the received message is correct
		MIC_OK,				//3		Message Integrity Checksum is correct.
		MIC_NOK_OTAA,		//4		MIC of the OTAA message is incorrect.
		MIC_NOK_MESSAGE,	//5		MIC of the received message is incorrect.
		ADDRESS_OK,			//6		Device address of the received message matches that of this LoRaWAN mote.
		ADDRESS_NOK,		//7		The device address of the received message doesn't match to the dev address of this mote.
		MAC_HEADER_NOK,		//8		Message header has an incorrect value, not matching any LoRaWAN headers
		RX_TIMEOUT,			//9		The RFM hasn't receive any message and got a time-out instead.
		OTAA_POINTER,		//10	Over The Air Activation structure has an incorrect pointer
		RX_MESSAGE,			//11	Message received.
		OTAA_COMPLETE,		//12	OTAA has been successfully completed.
		NEW_MESSAGE,		//13	When a new message has been received.
		DEFAULT_MAC,		//14	When a message is received with an invalid MAC header, this return value will be send back.
		LORA_POINTER_INVALID//15	Invalid Lora pointer
	}RFM_RETVAL;
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

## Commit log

2018-10-01 Included all drawings
    [Beep_Tube__2018_07_23.stp, Beep_tube__2018_07_23.stl, Beep_weightsensor_bracket__2018-05-10.stp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]
2018-10-01 Added PCB files
    [Beep_Tube__2018_07_23.stp, Beep_tube__2018_07_23.stl, Beep_weightsensor_bracket__2018-05-10.stp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]
2018-11-12 Bug in PCB: Changed One wire DS18b20 sensor from A7 to A4
    There is an error in the PCB, the one wire temperature sensor DS18b20 cannot work on analog port A7 (the A6 and A7 IO pins can only be used as analog pins, not as digital IO). So you have to use A4, or A5 to connect the one wire sensor.
    [Beep-low-power.ino]

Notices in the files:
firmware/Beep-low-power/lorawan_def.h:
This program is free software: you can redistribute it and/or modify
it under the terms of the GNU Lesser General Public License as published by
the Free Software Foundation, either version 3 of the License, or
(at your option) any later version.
